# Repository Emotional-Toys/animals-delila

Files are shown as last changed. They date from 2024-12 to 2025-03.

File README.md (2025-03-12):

## animals-delila

The friend model of the animals platform.

### History

Based upon fred with a push to a complete encompassed model. Am working on a new model that will have more of a fred look with the features of 2019s [the-name].

### Index of Features

* Computer [Cooling](/fan/README.md) control
* System [power](/power/README.md) management
* Build [structure](/structure/README.md)

### Progress

* 10.03.2025: Power management has been solved and the arrangment implemented. A consequence of the choice is that further modification is required to the housing and the size available to the external battery contemplatable. As a matter of operation: The device is _always on_ except when the battery expires. Hence, nofication is confined to a lit LED at a certain level

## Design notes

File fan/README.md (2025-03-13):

## CPU temperature control

To control the temperature of a RaspberryPi 4, mounted inside a chamber of a huggable, pettable plush robot:

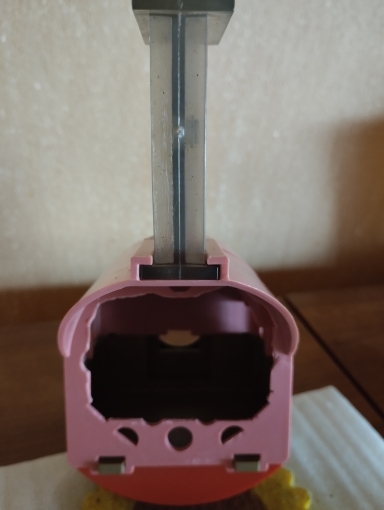
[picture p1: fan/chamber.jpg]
chamber


Using the GeekWorm Model P165-A 7mm Embedded Armor [heatsink](https://wiki.geekworm.com/P165), 

According to this [info](https://www.instructables.com/PWM-Regulated-Fan-Based-on-CPU-Temperature-for-Ras/), a small fan can be controlled with PWM to run when the temperature reaches a certain level, as for the Pi5. The parts needed are, although this is achievable on the [Pi4](https://howchoo.com/pi/control-raspberry-pi-fan-temperature-python/):

* 5V Fan
* NPN transistor that supports at least 300mA, like a 2N2222A
* 1K resistor
* 1 diode

With the following circuit diagram:

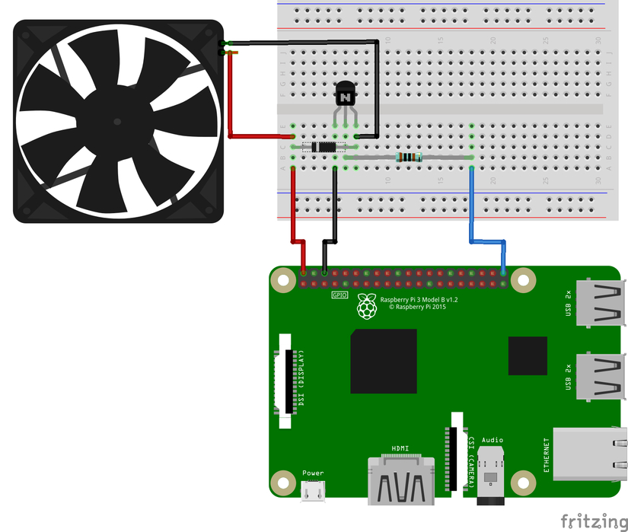
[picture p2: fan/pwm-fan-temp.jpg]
diagram


## Controlling fan speed according to temperature

To control fan speed, we use a software PWM signal from the RPi.GPIO library. A PWM Signal is well adapted to drive electric motors, as their reaction time is very high compared to the PWM frequency.

Use the calib_fan.py program to find the FAN_MIN value by running in the terminal:

python calib_fan.py

Check several values between 0 and 100% (should be around 20%) and see what is the minimum value for your fan to turn on.

You can change the correspondence between temperature and fan speed at the beginning of the code. There must be as many tempSteps as speedSteps values. This is the method that is generally used in PC motherboards, moving points on a Temp / Speed 2-axis graph.

## Run the program at startup

To run the program automatically at startup, I made a bash script where I put all the programs I want to launch, and then I launch this bash script at startup with `rc.locale`

Create a directory /home/cartheur/Scripts/ and place the `fan_ctrl.py` file inside that directory. In the same directory, copy the file launcher.sh. Edit `/etc/rc.locale` file and add a new line before the `"exit 0": sudo sh '/home/pi/Scripts/launcher.sh'`.

If you want to use it with OSMC for example, you need to start it as a service with `systemd`.

* Download the cooling.service file.
* Check the path to your python file.
* Place cooling.service in `/lib/systemd/system`.
* Enable the service with `sudo systemctl enable cooling.service`.

This method is safer, as the program will be automatically restarted if killed by the user or the system.

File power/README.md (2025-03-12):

## Using a high-capacity external battery

After getting into a big mess with the Waveshare HAT, choice of the PiJuice was better. Looking at the matter of not using the battery that came with the hat, there is [this](https://learn.pi-supply.com/make/how-to-setup-connect-your-pijuice-battery/). The key of this is that the battery is _not_ in the neighborhood, so the wires are connected according to the figure:

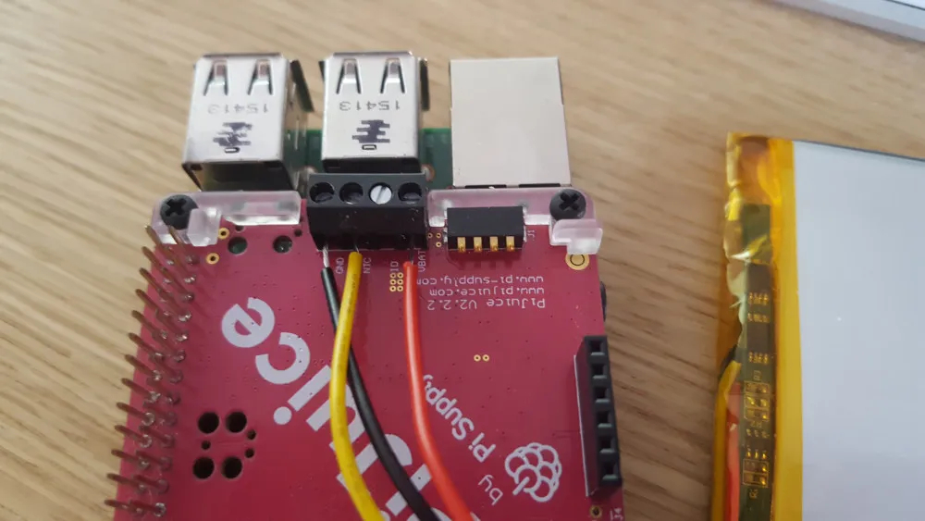
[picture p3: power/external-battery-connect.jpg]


## Indicating charge level

In the most simple case, according to a method for [arduino](https://www.instructables.com/DIY-Battery-Level-Checker/), this is transformed for pi. The idea is to have a simple battery checker that will have an LED light up indicator to tell the user how much power a battery contains to indicate whether or not to apply an external source to the power input on the robot. A future version would have a single LED that has the following behaviour:

* LED lights when battery level is > 50%
* LED blinks once every five seconds when level is > 25%
* LED blinks one every second when level is > 10%

the level-LED behaviour is modeled after the colour scheme of the [PiJuice](https://github.com/PiSupply/PiJuice/blob/master/Hardware/README.md).

_Things needed_

* Arduino or RaspberryPi
* Zener Diode
* 5mm Red LED
* 5mm Green LED
* 5mm Yellow LED
* 3x 100Ω Resistor
* 1x 2.2kΩ Resistor
* 3.7V LiPo for calibration

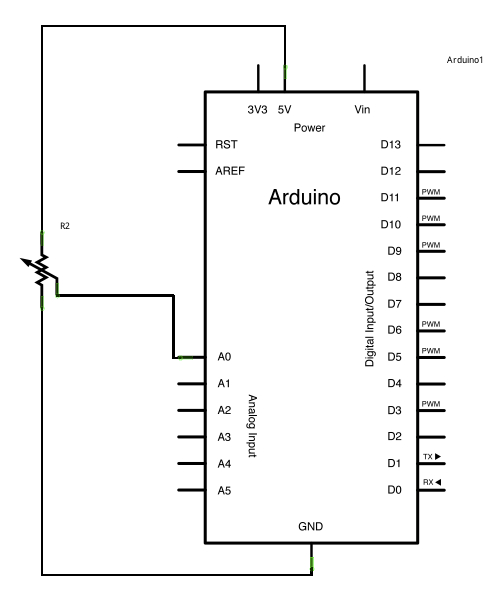
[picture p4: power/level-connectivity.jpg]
level


The Arduino's pins, by definition, reads the voltage levels of the signal. However, feeding raw input from the battery can damage the Arduino. This is where the 2.2k Ω resistor comes in. It reduces the current from the battery to a readable value for the Arduino without damaging it, since the pins have a current input limit.

The Zener diode allows us to test batteries that have a voltage greater than 8 volts. A Zener diode, like all other diode ensures that current will flow in only one direction until it hits a voltage threshold, which is dependent on the diode type. For a Zener diode, the limit is around 5.1V. When this limit is reached, current can go in the reverse direction. This is important since it is used to protect the Arduino from over-voltage.

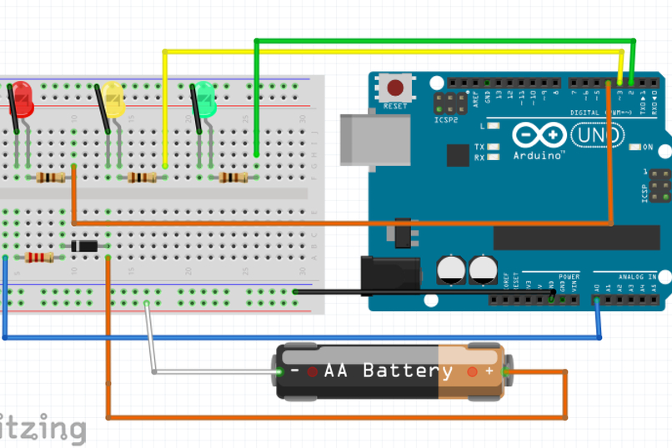
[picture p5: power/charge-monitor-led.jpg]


### LED Battery Indicator

The LED battery indicator will be in order of red, yellow, then green, where red means low, yellow is medium, and green is high or full.

* Connect the cathodes of each of the LEDs to the ground rail on the breadboard.
* Connect the anodes of each of the LEDs to it's own 100Ω resistor. Then connect the other end of each of the resistors to a jumper wire to pins 2,3 and 4, respectively.
* Green LED: pin 2
* Yellow LED: pin 3
* Red LED: pin 4
* Connect the ground rail on the breadboard to the GND pin on the Arduino

### Battery Checker

* Connect the 2.2kΩ resistor to A0.
* Connect the other end of this 2.2kΩ resistor to the negative end of the zener diode, indicated by the black bar.
* Connect the end of the free end of the diode to an orange jumper wire. This will connect to the positive terminal of any battery you want to test
* Connect a white jumper wire on the ground rail on the breadboard. This will connect to the negative terminal of any battery you want to test.
* The zener diode is veryimportant as it is used to protect the Arduino if the battery has a lot of charge left. Note the polarity of the zener diode, since it will be used to only allow current to flow in one direction!

### Code

```
int greenLed = 2;
int yellowLed = 3;
int redLed = 4;
int analogValue = 0;
float voltage = 0;
int ledDelay = 1000;
void setup()
{
  pinMode(greenLed, OUTPUT);
  pinMode(yellowLed,OUTPUT);
  pinMode(redLed,OUTPUT);
}
void loop()
{
  analogValue = analogRead(A0);
  voltage = 0.0048*analogValue;
  
  if( voltage >= 1.6 )
    digitalWrite(greenLed, HIGH);
  else if (voltage > 1.2 && voltage < 1.6)
    digitalWrite(yellowLed, HIGH);
  else if( voltage <= 1.2)
    digitalWrite(redLed, HIGH);  
 
  delay(ledDelay);
  digitalWrite(redLed, LOW);
  digitalWrite(yellowLed, LOW); 
  digitalWrite(greenLed, LOW);
}
```

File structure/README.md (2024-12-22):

## The delila project

A subtend of huggable but invented prior in 2019.

### The _models_ folder

The models necessary to engineer to have a pi fit into delila's chest cavity:

* The lower board [holder](/delila/models/delila-board-holder.stl)

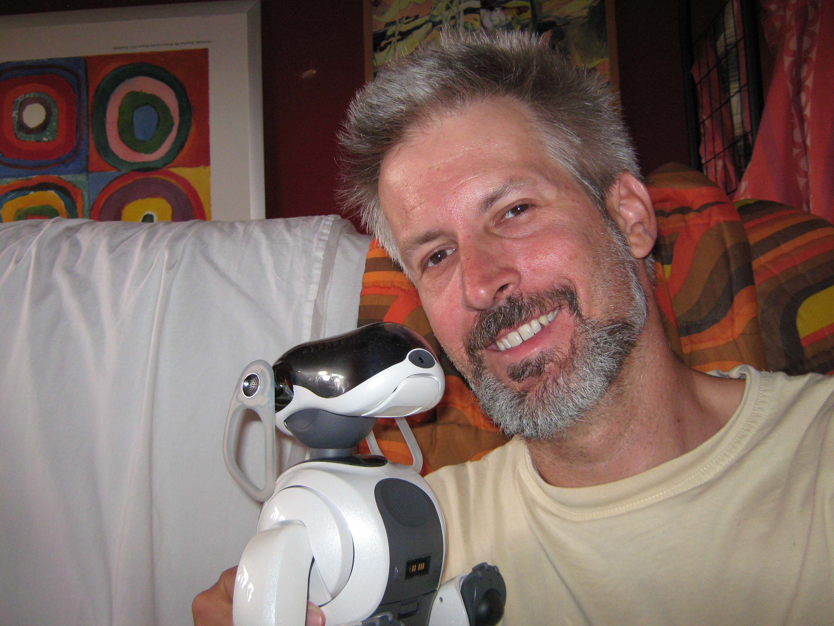
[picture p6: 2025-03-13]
fan/me-n-aibo.jpg

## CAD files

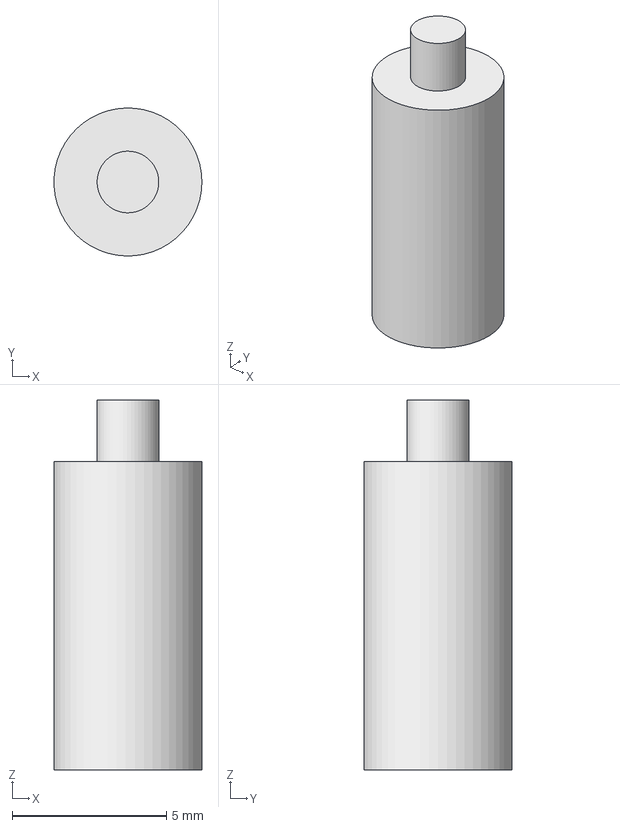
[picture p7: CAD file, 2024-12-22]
structure/models/delila-board-seat-pin.FCStd
4.80 x 4.80 x 12.0 mm

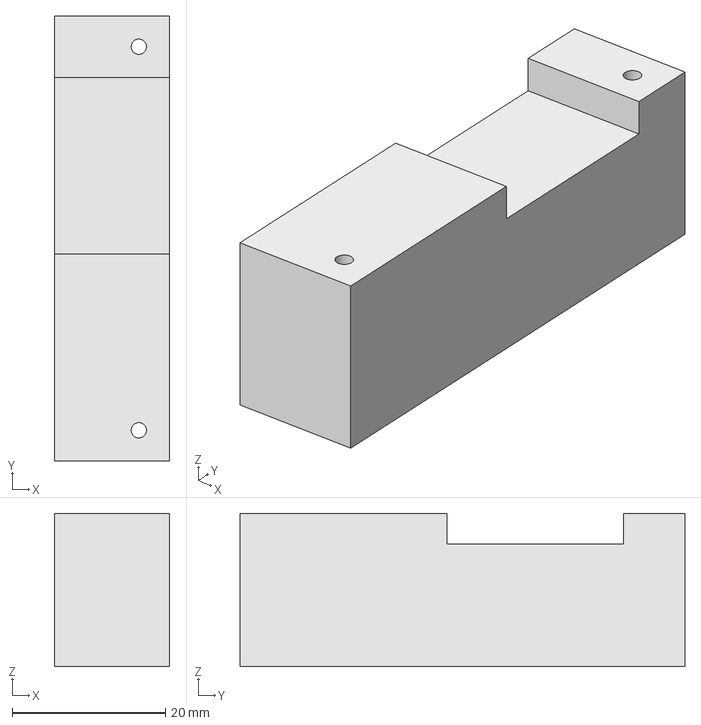
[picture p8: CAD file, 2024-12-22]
structure/models/delila-board-holder.FCStd
15.0 x 58.0 x 20.0 mm

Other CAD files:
structure/models/delila-board-holder.stl
structure/models/delila-board-seat-pin.stl

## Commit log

2024-12-22 Add structures
    [delila-board-holder.FCStd, delila-board-holder.stl, delila-board-seat-pin.FCStd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]
2025-03-12 Add landing
